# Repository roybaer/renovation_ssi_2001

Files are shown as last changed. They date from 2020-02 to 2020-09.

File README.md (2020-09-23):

# Renovation SSI-2001

This repository contains the design files for the _Renovation SSI-2001_ sound card, a replica of the _Innovation SSI-2001_ with some unobtrusive modifications that eliminate the dependency on vintage parts.
The Innovation SSI-2001 was an 8-bit ISA sound card from the late 1980s that was based on Commodore's SID synthesizer chip.

This modified design can optionally use an STM32 microcontroller, instead.
It can also use two NE556 dual timer ICs instead of a single NE558 quad timer IC for the integrated analog joystick interface.
All optional modern replacement components share the location of the vintage parts they replace, so that the modifications are largely invisible in combination with vintage parts.

## Front view

This picture shows the front of the card.

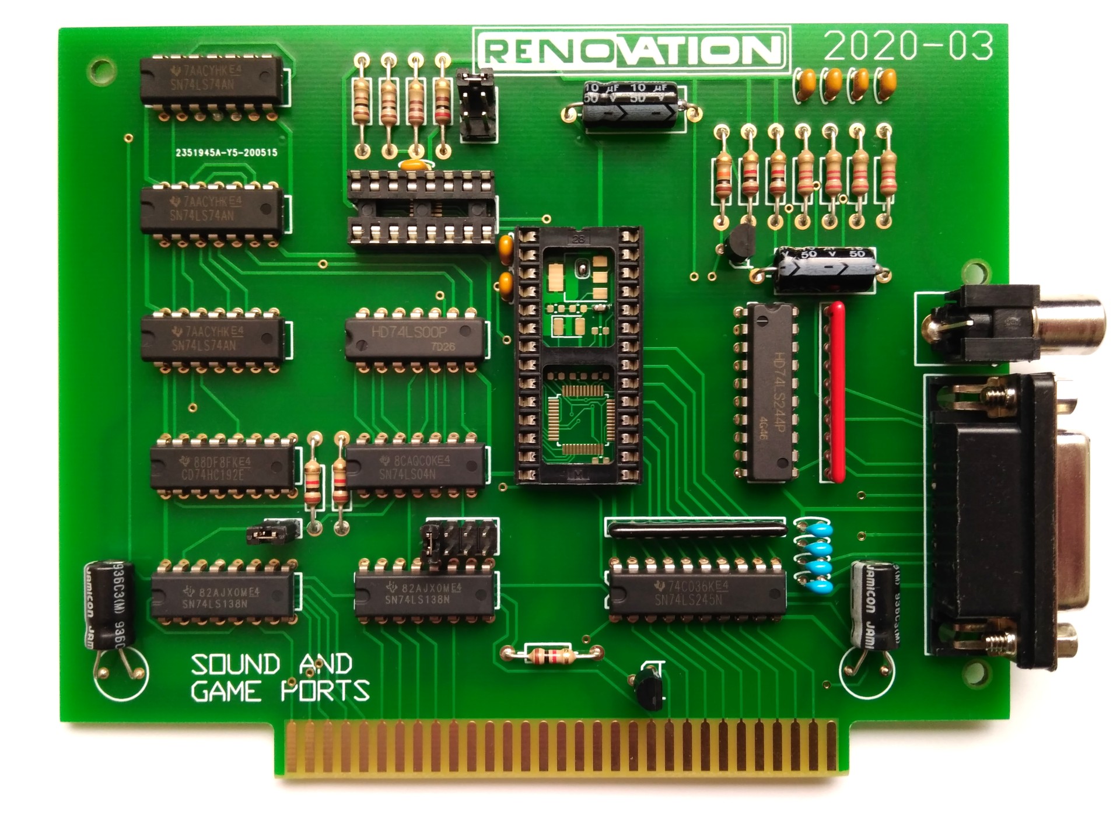
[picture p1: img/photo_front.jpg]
Front view


There is also a picture of the [back side of the card](img/photo_back.jpg).

## Optional vintage components

You will need the following vintage components for a visually accurate replica:

- A SID chip (MOS 6581 or MOS 8580, the latter with a hidden voltage regulator)
- An NE558 quad timer IC for the joystick interface

## Bill of materials

The design files of this project combine multiple possible hardware configurations in the same schematic diagram and PCB layout.
Hence, the unmodified tool-generated BOM will not yield a sensible hardware configuration.
Please read the notes in the schematic diagram, decide which variant you want to build and adjust the BOM, accordingly.

## Configuration

Please consult the [settings document](doc/settings.md) for jumper settings.

## Additional notes

The planned adaptation of the [STM32-SID-PLAYER](https://github.com/Bakisha/STM32-SID-PLAYER) firmware for this card, i.e. the implementation of an ISA interface for the synthesizer core is still pending.
Right now, this card is therefore only usable in combination with either an original SID or a modern substitute like the SwinSID.

The exact DA15 and RCA connectors found on the original card are no longer available and have therefore been replaced by affordable modern variants.
Furthermore, the RCA jack and the mounting holes have been shifted to simplify the adaptation of the generic Keystone 9202 ISA bracket.

## License

The following license applies to the files in this repository:

This work is licensed under the Creative Commons Attribution-ShareAlike 4.0 International License. To view a copy of this license, visit http://creativecommons.org/licenses/by-sa/4.0/ or send a letter to Creative Commons, PO Box 1866, Mountain View, CA 94042, USA.

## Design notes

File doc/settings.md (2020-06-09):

# Jumper settings

Both, the audio section and the joystick section of the card can be configured with jumpers.
This document lists all sensible jumper settings.

## Audio section

The audio section can be configured to use at most one out of four possible I/O port ranges.

Setting | Meaning
--------|--------
░░░░    | Audio disabled
█░░░    | Ports 280h to 29fh
░█░░    | Ports 2a0h to 2bfh
░░█░    | Ports 2c0h to 2dfh
░░░█    | Ports 2e0h to 2ffh

## Joystick section

The built-in IBM compatible analog joystick interface at port 201h can be en- or disabled and its sensitivity can be adjusted.
The jumper positions of vertical jumper banks are shown from left to right rather than from top to bottom.

Setting | Meaning
--------|--------
░       | Joystick disabled
█       | Joystick enabled

Setting | Meaning
--------|--------
░░░     | Normal sensitivity
█░░     | High sensitivity
░█░     | Normal sensitivity
░░█     | Low sensitivity

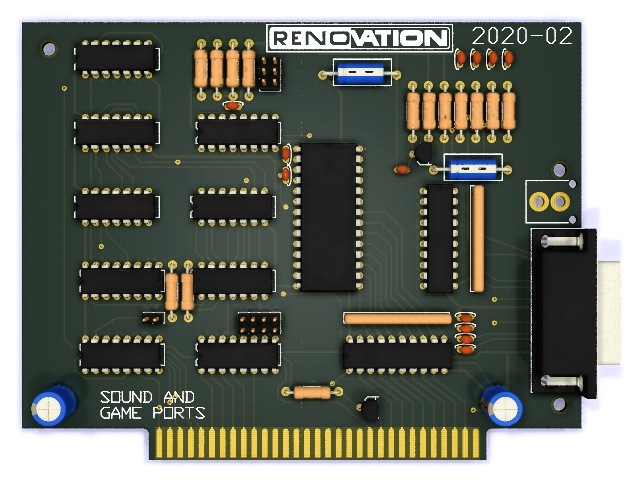
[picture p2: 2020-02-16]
img/rendering_front.jpg

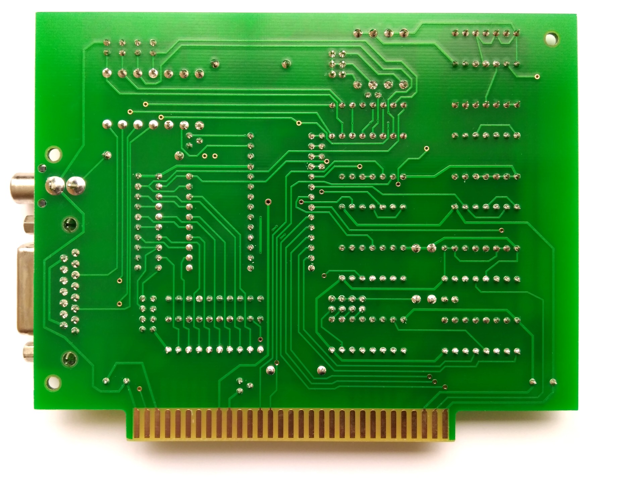
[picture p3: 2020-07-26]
img/photo_back.jpg

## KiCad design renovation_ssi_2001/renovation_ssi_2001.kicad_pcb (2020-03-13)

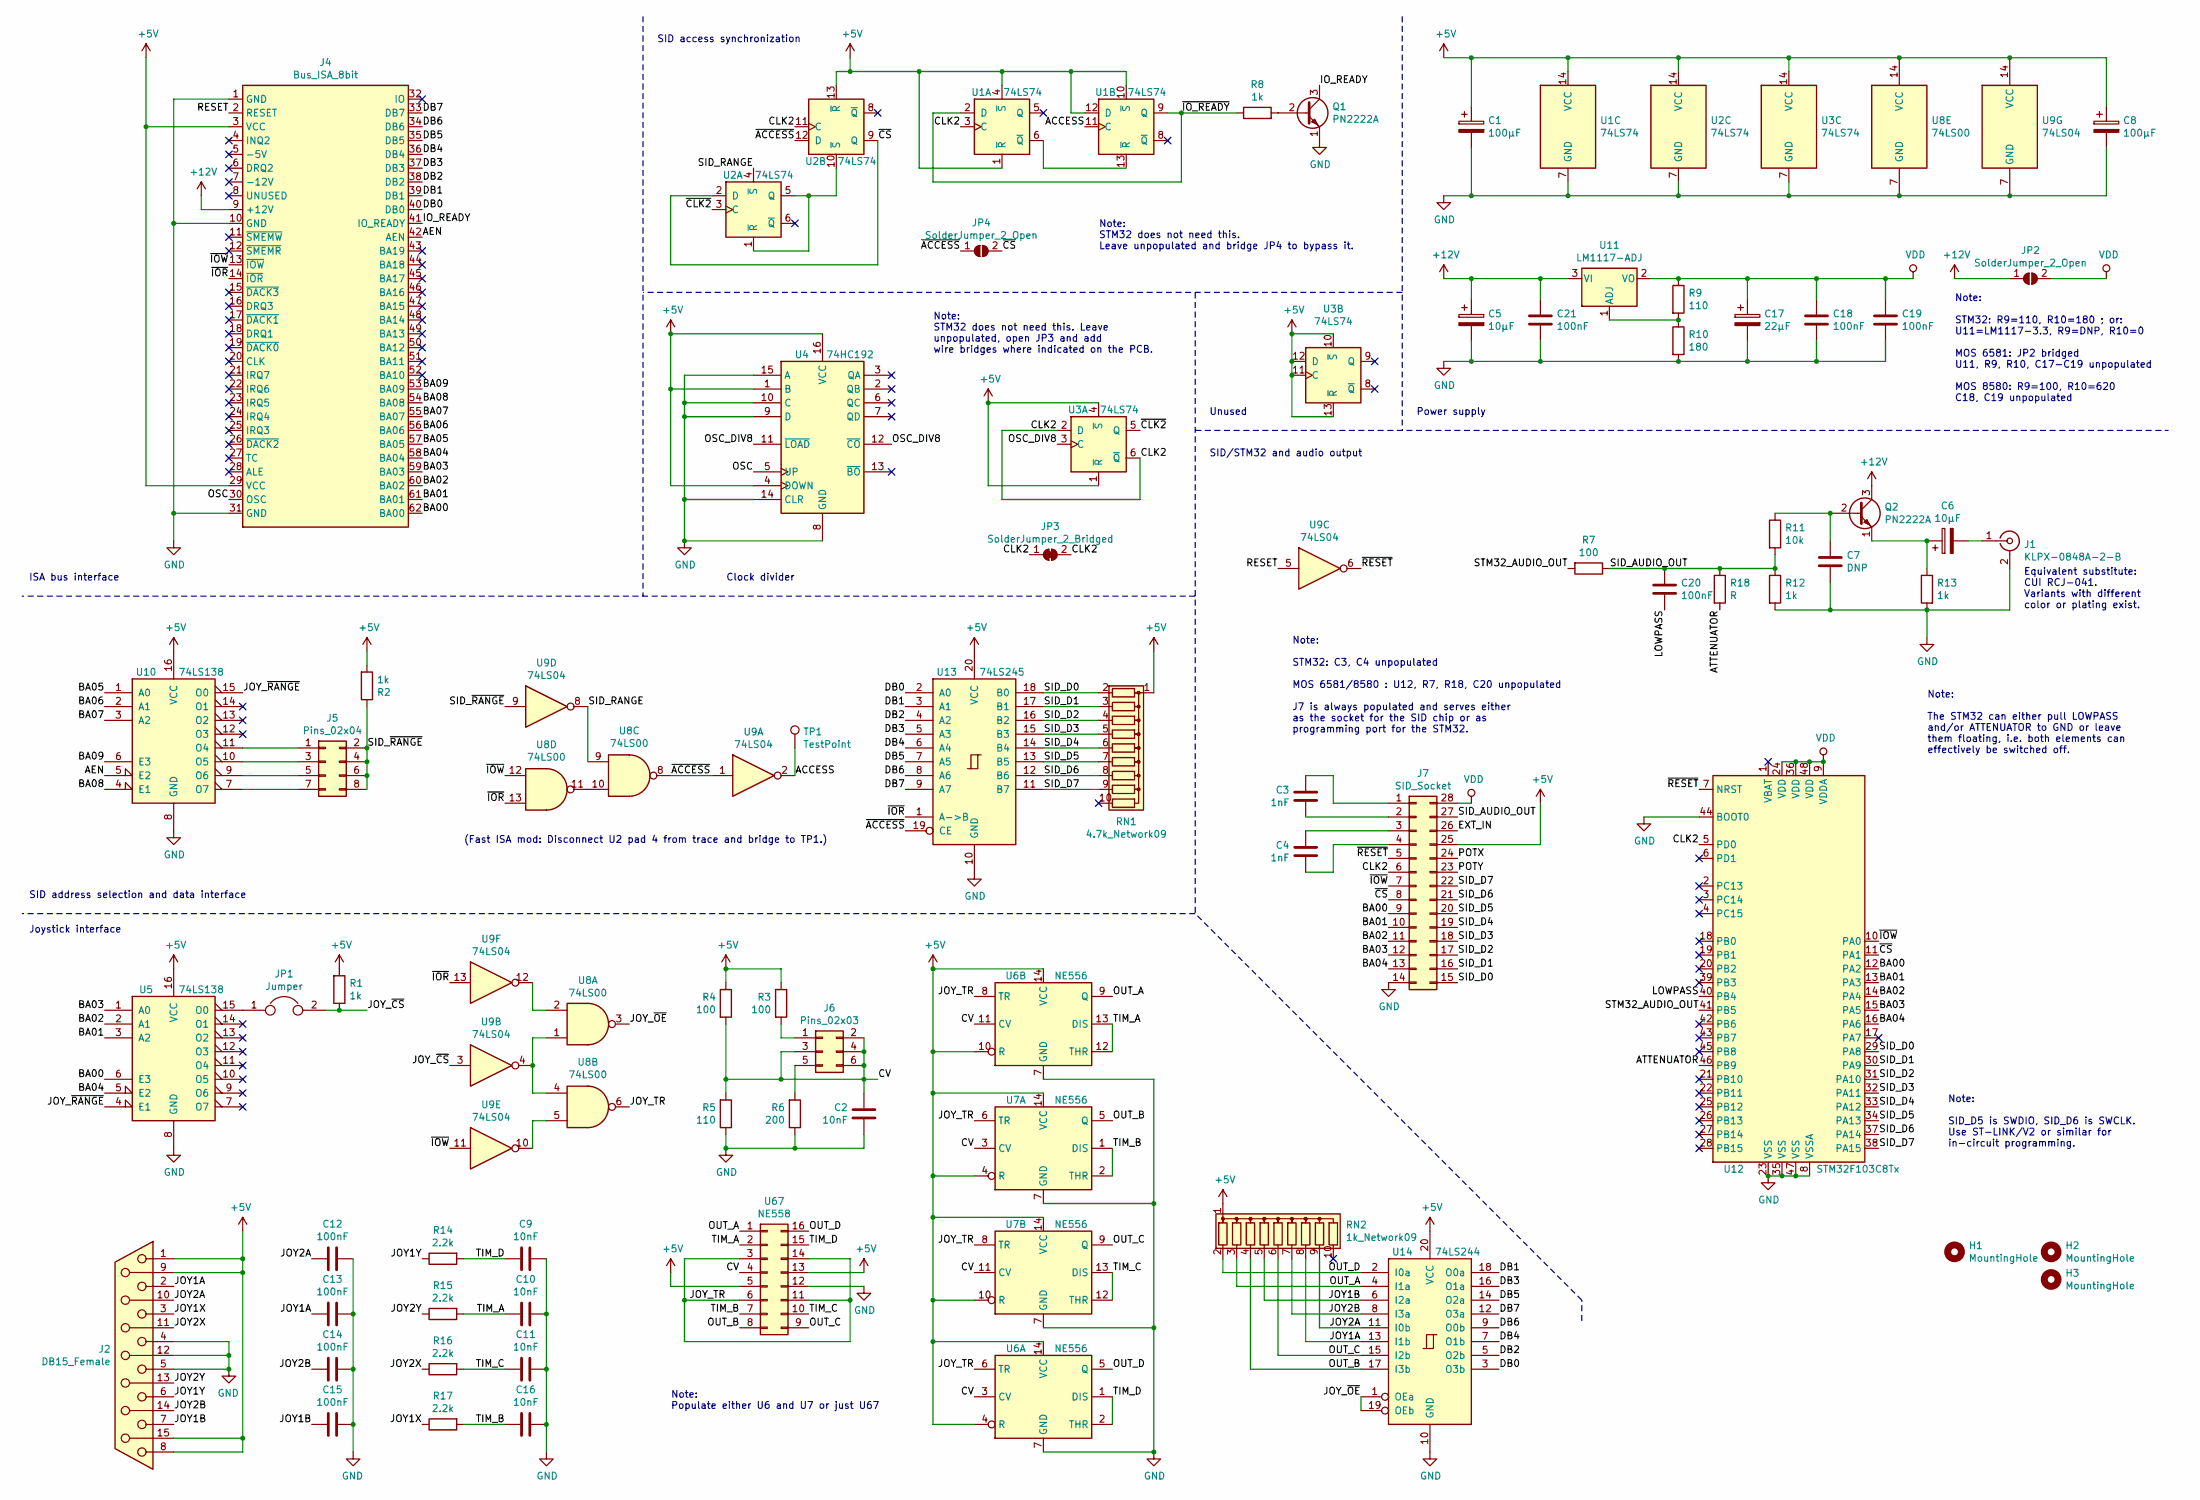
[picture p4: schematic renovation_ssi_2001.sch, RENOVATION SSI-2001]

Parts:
C1, C8: 100µF; CP_Radial_D6.3mm_P2.50mm
C2, C9, C10, C11, C16: 10nF; C_Disc_D3.4mm_W2.1mm_P2.50mm
C3, C4: 1nF; C_Disc_D3.4mm_W2.1mm_P2.50mm
C5, C6: 10µF; CP_Axial_L11.0mm_D5.0mm_P18.00mm_Horizontal
C7: DNP; C_Disc_D3.4mm_W2.1mm_P2.50mm_alt
C12, C13, C14, C15: 100nF; C_Disc_D3.4mm_W2.1mm_P2.50mm
C17: 22µF; CP_EIA-3528-21_Kemet-B
C18, C19, C20, C21: 100nF; C_0603_1608Metric
H1, H2, H3: MountingHole; MountingHole_3.2mm_M3
J1: KLPX-0848A-2-B; Cinch_Kycon_KLPX-0848A-2-B
J2: DB15_Female; DSUB-15_Female_Horizontal_P2.77x2.84mm_EdgePinOffset7.70mm_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
J4: Bus_ISA_8bit; BUS_XT
J5: Pins_02x04; PinHeader_2x04_P2.54mm_Vertical
J6: Pins_02x03; PinHeader_2x03_P2.54mm_Vertical
J7: SID_Socket; DIP-28_W15.24mm
JP1: Jumper; PinHeader_1x02_P2.54mm_Vertical
JP2, JP4: SolderJumper_2_Open; SolderJumper-2_P1.3mm_Open_RoundedPad1.0x1.5mm
JP3: SolderJumper_2_Bridged; SolderJumper-2_P1.3mm_Bridged_RoundedPad1.0x1.5mm
Q1, Q2: PN2222A; TO-92
R1, R2, R8, R12, R13: 1k; R_Axial_DIN0309_L9.0mm_D3.2mm_P12.70mm_Horizontal
R3, R4: 100; R_Axial_DIN0309_L9.0mm_D3.2mm_P12.70mm_Horizontal
R5: 110; R_Axial_DIN0309_L9.0mm_D3.2mm_P12.70mm_Horizontal
R6: 200; R_Axial_DIN0309_L9.0mm_D3.2mm_P12.70mm_Horizontal
R7: 100; R_0603_1608Metric
R9: 110; R_0603_1608Metric
R10: 180; R_0603_1608Metric
R11: 10k; R_Axial_DIN0309_L9.0mm_D3.2mm_P12.70mm_Horizontal
R14, R15, R16, R17: 2.2k; R_Axial_DIN0309_L9.0mm_D3.2mm_P12.70mm_Horizontal
R18: R; R_0603_1608Metric
RN1: 4.7k_Network09; R_Array_SIP10
RN2: 1k_Network09; R_Array_SIP10
TP1: TestPoint; TestPoint_Pad_1.5x1.5mm
U1, U2, U3: 74LS74; DIP-14_W7.62mm
U4: 74HC192; DIP-16_W7.62mm
U5, U10: 74LS138; DIP-16_W7.62mm
U6, U7: NE556; SSOP-14_5.3x6.2mm_P0.65mm
U8: 74LS00; DIP-14_W7.62mm
U9: 74LS04; DIP-14_W7.62mm
U11: LM1117-ADJ; SOT-223-3_TabPin2
U12: STM32F103C8Tx; LQFP-48_7x7mm_P0.5mm
U13: 74LS245; DIP-20_W7.62mm
U14: 74LS244; DIP-20_W7.62mm
U67: NE558; DIP-16_W7.62mm

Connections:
+5V: C1.1, C8.1, J2.1, J2.8, J2.9, J2.15, J4.3 (VCC), J4.29 (VCC), J7.25, R1.2, R2.2, R3.1, R4.1, RN1.1 (common), RN2.1 (common), U1.1 (~R), U1.4 (~S), U1.10 (~S), U1.12 (D), U1.14 (VCC), U2.13 (~R), U2.14 (VCC), U3.1 (~R), U3.4 (~S), U3.10 (~S), U3.11 (C), U3.12 (D), U3.13 (~R), U3.14 (VCC), U4.1 (B), U4.4 (DOWN), U4.16 (VCC), U5.16 (VCC), U6.4 (R), U6.10 (R), U6.14 (VCC), U7.4 (R), U7.10 (R), U7.14 (VCC), U8.14 (VCC), U9.14 (VCC), U10.16 (VCC), U13.20 (VCC), U14.20 (VCC), U67.5, U67.13
+12V: C5.1, C21.1, J4.9 (+12V), JP2.1 (A), Q2.3 (C), U11.3 (VI)
/ACCESS: TP1.1, U1.11 (C), U9.2
/AEN: J4.42 (AEN), U10.5 (E2)
/ATTENUATOR: R18.2, U12.46 (PB9)
/BA00: J4.62 (BA00), J7.9, U5.6 (E3), U12.12 (PA2)
/BA01: J4.61 (BA01), J7.10, U5.3 (A2), U12.13 (PA3)
/BA02: J4.60 (BA02), J7.11, U5.2 (A1), U12.14 (PA4)
/BA03: J4.59 (BA03), J7.12, U5.1 (A0), U12.15 (PA5)
/BA04: J4.58 (BA04), J7.13, U5.5 (E2), U12.16 (PA6)
/BA05: J4.57 (BA05), U10.1 (A0)
/BA06: J4.56 (BA06), U10.2 (A1)
/BA07: J4.55 (BA07), U10.3 (A2)
/BA08: J4.54 (BA08), U10.4 (E1)
/BA09: J4.53 (BA09), U10.6 (E3)
/CLK2: J7.6, JP3.1 (A), JP3.2 (B), U1.3 (C), U2.11 (C), U3.2 (D), U3.6 (~Q), U12.5 (PD0)
/CV: C2.1, J6.2, J6.3, J6.4, J6.6, R4.2, R5.2, U6.3 (CV), U6.11 (CV), U7.3 (CV), U7.11 (CV), U67.4
/DB0: J4.40 (DB0), U13.2 (A0), U14.3 (O3b)
/DB1: J4.39 (DB1), U13.3 (A1), U14.18 (O0a)
/DB2: J4.38 (DB2), U13.4 (A2), U14.5 (O2b)
/DB3: J4.37 (DB3), U13.5 (A3), U14.16 (O1a)
/DB4: J4.36 (DB4), U13.6 (A4), U14.7 (O1b)
/DB5: J4.35 (DB5), U13.7 (A5), U14.14 (O2a)
/DB6: J4.34 (DB6), U13.8 (A6), U14.9 (O0b)
/DB7: J4.33 (DB7), U13.9 (A7), U14.12 (O3a)
/EXT_IN: J7.26
/IO_READY: J4.41 (IO_READY), Q1.3 (C)
/JOY1A: C13.2, J2.2, RN2.8 (R7), U14.13 (I1b)
/JOY1B: C15.2, J2.7, RN2.5 (R4), U14.6 (I2a)
/JOY1X: J2.3, R17.1
/JOY1Y: J2.6, R14.1
/JOY2A: C12.2, J2.10, RN2.9 (R8), U14.11 (I0b)
/JOY2B: C14.2, J2.14, RN2.7 (R6), U14.8 (I3a)
/JOY2X: J2.11 (P111), R16.1
/JOY2Y: J2.13, R15.1
/JOY_TR: U6.6 (TR), U6.8 (TR), U7.6 (TR), U7.8 (TR), U8.6, U67.3, U67.6, U67.11, U67.14
/JOY_~CS: JP1.2, R1.1, U9.3
/JOY_~OE: U8.3, U14.1 (OEa), U14.19 (OEb)
/JOY_~RANGE: U5.4 (E1), U10.15 (O0)
/LOWPASS: C20.2, U12.40 (PB4)
/OSC: J4.30 (OSC), U4.5 (UP)
/OSC_DIV8: U3.3 (C), U4.11 (~LOAD), U4.12 (~CO)
/OUT_A: RN2.3 (R2), U6.9 (Q), U14.4 (I1a), U67.1
/OUT_B: RN2.4 (R3), U7.5 (Q), U14.17 (I3b), U67.8
/OUT_C: RN2.6 (R5), U7.9 (Q), U14.15 (I2b), U67.9
/OUT_D: RN2.2 (R1), U6.5 (Q), U14.2 (I0a), U67.16
/POTX: J7.24
/POTY: J7.23
/RESET: J4.2 (RESET), U9.5
/SID_AUDIO_OUT: C20.1, J7.27, R7.1, R11.2, R12.1, R18.1
/SID_D0: J7.15, RN1.2 (R1), U12.29 (PA8), U13.18 (B0)
/SID_D1: J7.16, RN1.3 (R2), U12.30 (PA9), U13.17 (B1)
/SID_D2: J7.17, RN1.4 (R3), U12.31 (PA10), U13.16 (B2)
/SID_D3: J7.18, RN1.5 (R4), U12.32 (PA11), U13.15 (B3)
/SID_D4: J7.19, RN1.6 (R5), U12.33 (PA12), U13.14 (B4)
/SID_D5: J7.20, RN1.7 (R6), U12.34 (PA13), U13.13 (B5)
/SID_D6: J7.21, RN1.8 (R7), U12.37 (PA14), U13.12 (B6)
/SID_D7: J7.22, RN1.9 (R8), U12.38 (PA15), U13.11 (B7)
/SID_RANGE: U2.4 (~S), U8.9, U9.8
/SID_~RANGE: J5.2, J5.4, J5.6, J5.8, R2.1, U9.9
/STM32_AUDIO_OUT: R7.2, U12.41 (PB5)
/TIM_A: C10.1, R15.2, U6.12 (THR), U6.13 (DIS), U67.2
/TIM_B: C16.1, R17.2, U7.1 (DIS), U7.2 (THR), U67.7
/TIM_C: C11.1, R16.2, U7.12 (THR), U7.13 (DIS), U67.10
/TIM_D: C9.1, R14.2, U6.1 (DIS), U6.2 (THR), U67.15
/~ACCESS: JP4.1 (A), U2.12 (D), U8.8, U9.1, U13.19 (CE)
/~CLK2: U2.3 (C), U3.5 (Q)
/~CS: J7.8, JP4.2 (B), U2.2 (D), U2.9 (Q), U12.11 (PA1)
/~IOR: J4.14 (~IOR), U8.13, U9.13, U13.1 (A->B)
/~IOW: J4.13 (~IOW), J7.7, U8.12, U9.11, U12.10 (PA0)
/~IO_READY: R8.1, U1.2 (D), U1.9 (Q)
/~RESET: J7.5, U9.6, U12.7 (NRST)
GND: C1.2, C2.2, C5.2, C7.1, C8.2, C9.2, C10.2, C11.2, C12.1, C13.1, C14.1, C15.1, C16.2, C17.2, C18.2, C19.2, C21.2, J1.2 (Ext), J2.4, J2.5, J2.12, J4.1 (GND), J4.10 (GND), J4.31 (GND), J7.14, Q1.1 (E), R5.1, R6.1, R10.2, R12.2, R13.2, U1.7 (GND), U2.7 (GND), U3.7 (GND), U4.8 (GND), U4.9 (D), U4.10 (C), U4.14 (CLR), U4.15 (A), U5.8 (GND), U6.7 (GND), U7.7 (GND), U8.7 (GND), U9.7 (GND), U10.8 (GND), U12.8 (VSSA), U12.23 (VSS), U12.35 (VSS), U12.44 (BOOT0), U12.47 (VSS), U13.10 (GND), U14.10 (GND), U67.12
unnamed: C3.1, J7.1
unnamed: C3.2, J7.2
unnamed: C4.1, J7.3
unnamed: C4.2, J7.4
unnamed: C6.1, Q2.1 (E), R13.1
unnamed: C6.2, J1.1 (In)
unnamed: C7.2, Q2.2 (B), R11.1
unnamed: J5.1, U10.11 (O4)
unnamed: J5.3, U10.10 (O5)
unnamed: J5.5, U10.9 (O6)
unnamed: J5.7, U10.7 (O7)
unnamed: J6.1, R3.2
unnamed: J6.5, R6.2
unnamed: JP1.1, U5.15 (O0)
unnamed: Q1.2 (B), R8.2
unnamed: R9.2, R10.1, U11.1 (ADJ)
unnamed: U1.6 (~Q), U1.13 (~R)
unnamed: U2.1 (~R), U2.5 (Q), U2.10 (~S)
unnamed: U8.1, U8.4, U9.4
unnamed: U8.2, U9.12
unnamed: U8.5, U9.10
unnamed: U8.10, U8.11
VDD: C17.1, C18.1, C19.1, J7.28, JP2.2 (B), R9.1, U11.2 (VO), U12.9 (VDDA), U12.24 (VDD), U12.36 (VDD), U12.48 (VDD)

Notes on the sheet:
Unused
Joystick interface
Power supply
SID access synchronization
SID address selection and data interface
Clock divider
ISA bus interface
SID/STM32 and audio output
Note: STM32: C3, C4 unpopulated MOS 6581/8580 : U12, R7, R18, C20 unpopulated J7 is always populated and serves either as the socket for the SID chip or as programming port for the STM32.
Note: Populate either U6 and U7 or just U67
Note: STM32 does not need this. Leave unpopulated and bridge JP4 to bypass it.
Note: STM32 does not need this. Leave unpopulated, open JP3 and add wire bridges where indicated on the PCB.
Note: The STM32 can either pull LOWPASS and/or ATTENUATOR to GND or leave them floating, i.e. both elements can effectively be switched off.
(Fast ISA mod: Disconnect U2 pad 4 from trace and bridge to TP1.)
Equivalent substitute: CUI RCJ-041. Variants with different color or plating exist.
Note: STM32: R9=110, R10=180 ; or: U11=LM1117-3.3, R9=DNP, R10=0 MOS 6581: JP2 bridged U11, R9, R10, C17-C19 unpopulated MOS 8580: R9=100, R10=620 C18, C19 unpopulated
Note: SID_D5 is SWDIO, SID_D6 is SWCLK. Use ST-LINK/V2 or similar for in-circuit programming.

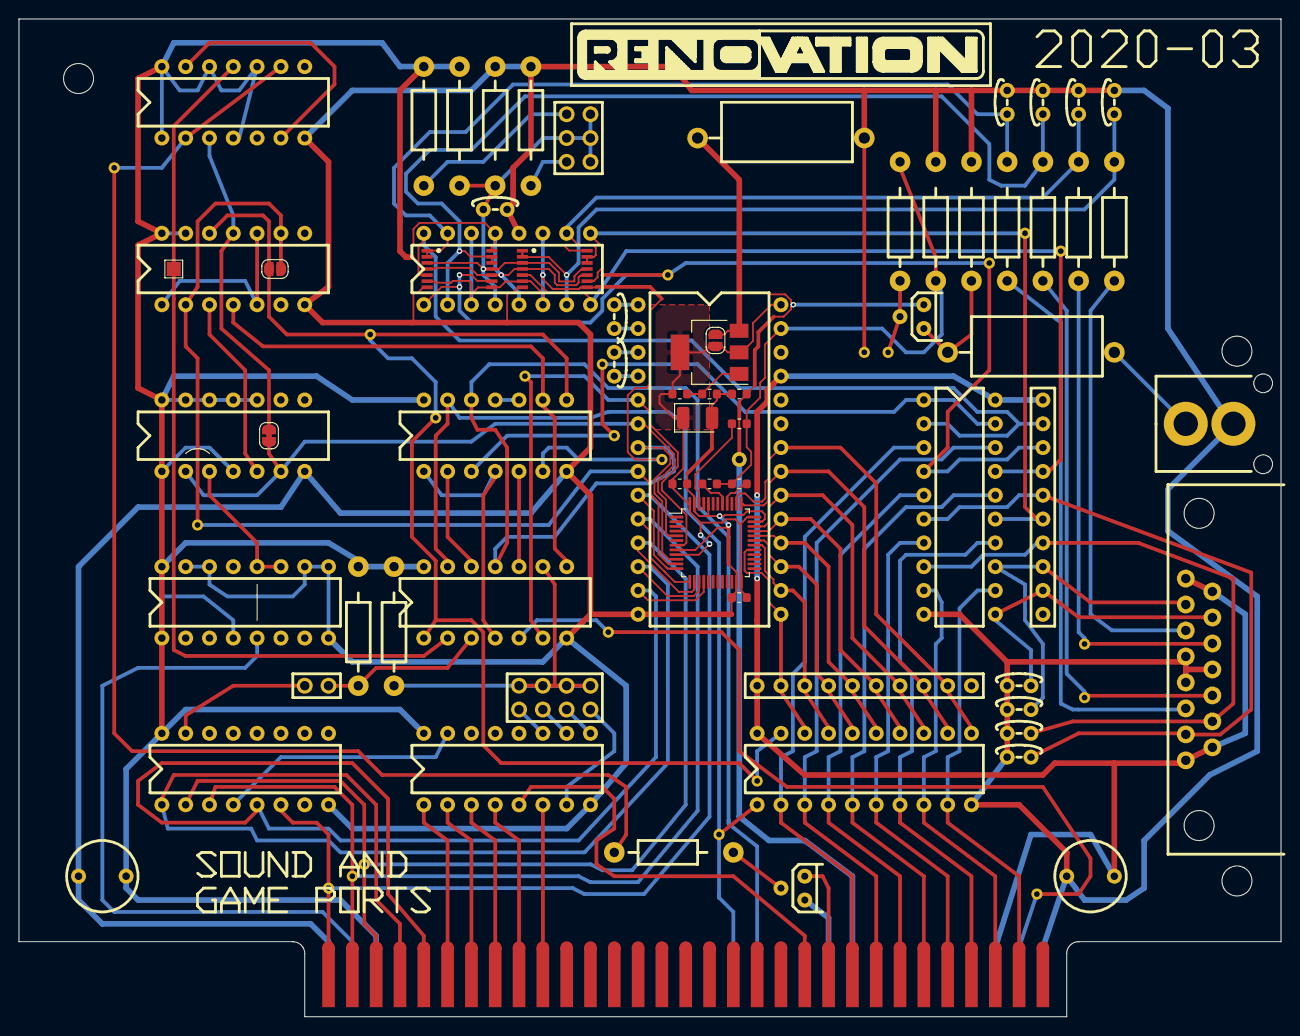
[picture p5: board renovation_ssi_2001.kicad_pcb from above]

Board: 2 copper layers, 134.6 x 106.4 mm, 72 parts (0 on the bottom side), 93 nets.

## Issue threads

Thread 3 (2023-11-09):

Resistor R18 Value?

nsinav, 2023-11-09:
Hello. I am trying to get the value of the resistor 0603 R18, but i only get R as value. Can you help me? Thanks.

roybaer, 2023-11-09:
You can ignore that. The support circuitry around the STM32 was designed with both, filtered PWM output or, alternatively, S/PDIF output in mind, but actually, neither has been implemented so far. R18 would have been there to tune the output level.
I.e. you either have to write the firmware for the STM32 yourself – ideally based on existing SID emulation code – or omit it entirely and use a real SID or drop-in replacement, instead.
The schematic contains notes on which parts are required for which configuration.
A configuration with MOS 6581, for instance, does not need any SMD components at all, but does need a solder bridge below the socket, if I remember correctly.

Closed 2023-11-09.

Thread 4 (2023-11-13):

Dangling line on the Top layer

nsinav, 2023-11-13:
Hello,
I have a question. Recently I found that there is a dangling line on the Top layer, as shown in the figure below. Does this affect the function? I send you pics. Thank you.
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

roybaer, 2023-11-13:
It doesn't, because it is there for looks, only.
The historical layout of the Innovation SSI-2001 ran a trace from that VIA to pin 1 of the NE558 on the top layer below the chip, but this modified layout hides the footprints for optional modern replacements under there, so that pin 1 is now connected via a new trace on the bottom layer.

nsinav, 2023-11-14:
Thank you sir, you are very kind

Closed 2023-11-13.

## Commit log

2020-03-08 corrections and improvements
    [renovation_ssi_2001.kicad_pcb, renovation_ssi_2001.sch]
2020-03-10 fill in some component values, add pad to simplify fast ISA mod, adjust mounting hole positions
    [renovation_ssi_2001.kicad_pcb, renovation_ssi_2001.sch]
2020-03-13 correct configuration resistor values for the voltage regulator
    [renovation_ssi_2001.kicad_pcb, renovation_ssi_2001.sch]
